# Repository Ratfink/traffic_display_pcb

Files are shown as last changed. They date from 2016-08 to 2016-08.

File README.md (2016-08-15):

# traffic_display_pcb
PCB for the Traffic Signal LED Matrix Display.

## Licensing
This work is licensed under the Creative Commons Attribution-ShareAlike 4.0
International License. To view a copy of this license, visit
http://creativecommons.org/licenses/by-sa/4.0/ or send a letter to Creative
Commons, PO Box 1866, Mountain View, CA 94042, USA.

Around half of the schematic is heavily based on the [Adafruit Feather ESP8266
HUZZAH](https://github.com/adafruit/Adafruit-Feather-ESP8266-HUZZAH-PCB).
Although Adafruit seems to have forgotten to include the exact version of the
Creative Commons Attribution-ShareAlike license used (at the time of writing),
and this project is not really a redistribution of theirs, I will include their
text as requested to try to avoid treading on any legal toes.

### Adafruit-Feather-ESP8266-HUZZAH-PCB

PCB files for the Adafruit Feather ESP8266 HUZZAH

Format is EagleCAD schematic and board layout

For more details, check out the product page at

* https://www.adafruit.com/product/2821

Adafruit invests time and resources providing this open source design, please
support Adafruit and open-source hardware by purchasing products from Adafruit!

Designed by Adafruit Industries.  
Creative Commons Attribution, Share-Alike license, check license.txt for more
information All text above must be included in any redistribution

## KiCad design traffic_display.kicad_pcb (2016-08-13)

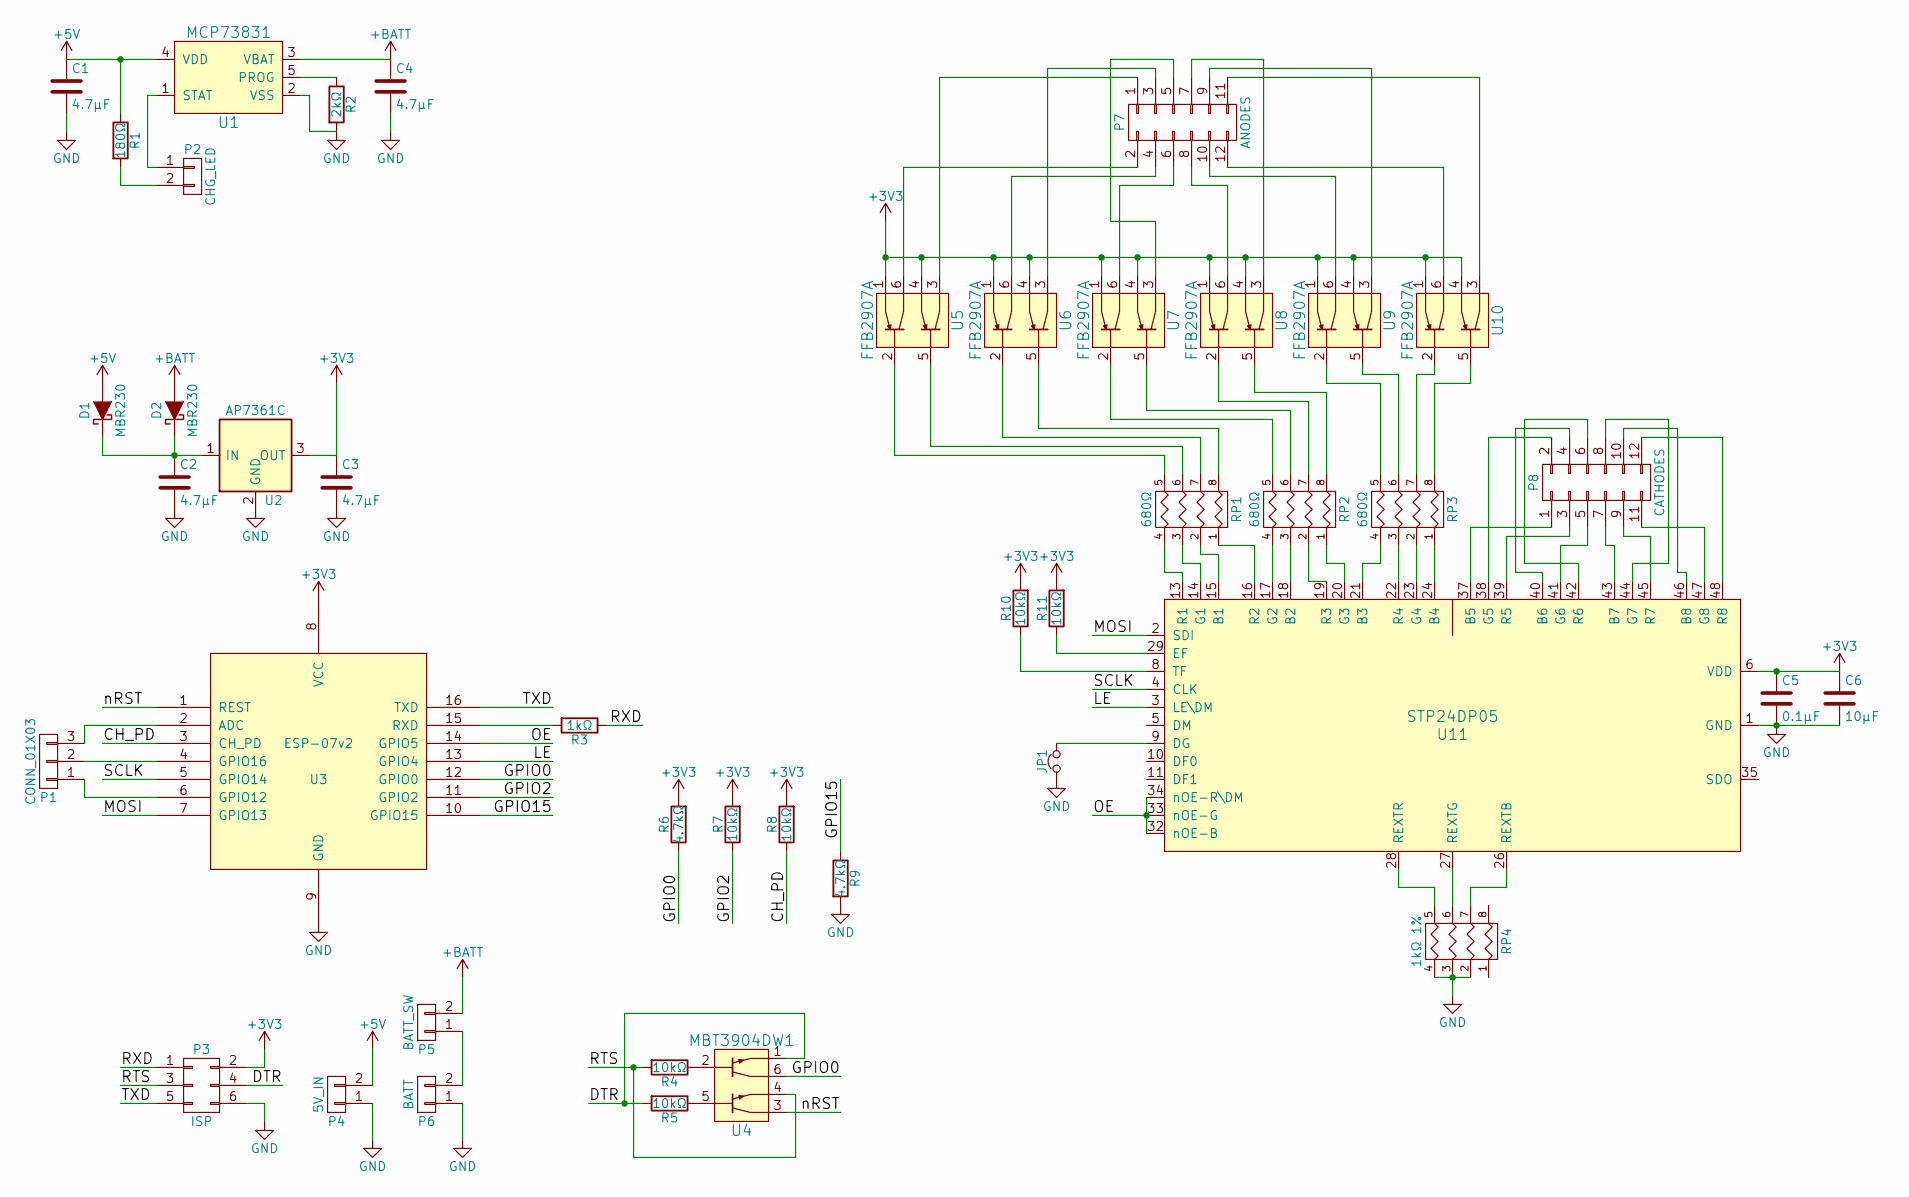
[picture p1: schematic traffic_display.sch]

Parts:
C1, C2, C3, C4: 4.7µF; C_0805_HandSoldering
C5: 0.1µF; C_0805_HandSoldering
C6: 10µF; C_0805_HandSoldering
D1, D2: MBR230; SOD-123
JP1: Jumper_NC_Small; R_0805_HandSoldering
P1: CONN_01X03; Pin_Header_Straight_1x03
P2: CHG_LED; Molex_KK-6410-02_02x2.54mm_Straight
P3: ISP; Pin_Header_Straight_2x03
P4: 5V_IN; Molex_KK-6410-02_02x2.54mm_Straight
P5: BATT_SW; Molex_KK-6410-02_02x2.54mm_Straight
P6: BATT; Molex_KK-6410-02_02x2.54mm_Straight
P7: ANODES; Pin_Header_Straight_2x06
P8: CATHODES; Pin_Header_Straight_2x06
R1: 180Ω; R_0805_HandSoldering
R2: 2kΩ; R_0805_HandSoldering
R3: 1kΩ; R_0805_HandSoldering
R4, R5, R7, R8, R10, R11: 10kΩ; R_0805_HandSoldering
R6, R9: 4.7kΩ; R_0805_HandSoldering
RP1, RP2, RP3: 680Ω; R_Array_Concave_4x0603
RP4: 1kΩ 1%; R_Array_Concave_4x0603
U1: MCP73831; SOT-23-5
U2: AP7361C; SOT-223
U3: ESP-07v2
U4: MBT3904DW1; SC-70-6_Handsoldering
U5, U6, U7, U8, U9, U10: FFB2907A; SC-70-6_Handsoldering
U11: STP24DP05; TQFP-48-1EP_7x7mm_Pitch0.5mm

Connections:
+3V3: C3.1, C5.1, C6.1, P3.2, R6.2, R7.2, R8.2, R10.2, R11.2, U2.3 (OUT), U3.8 (VCC), U5.1 (E1), U5.4 (E2), U6.1 (E1), U6.4 (E2), U7.1 (E1), U7.4 (E2), U8.1 (E1), U8.4 (E2), U9.1 (E1), U9.4 (E2), U10.1 (E1), U10.4 (E2), U11.6 (VDD), U11.31 (VDD)
+5V: C1.1, D1.2 (A), P4.2, R1.1, U1.4 (VDD)
+BATT: C4.1, D2.2 (A), P5.2, U1.3 (VBAT)
/CH_PD: R8.1, U3.3 (CH_PD)
/DTR: P3.4, R5.2, U4.1 (E1)
/GPIO0: R6.1, U3.12 (GPIO0), U4.6 (C1)
/GPIO2: R7.1, U3.11 (GPIO2)
/GPIO15: R9.1, U3.10 (GPIO15)
/LE: U3.13 (GPIO4), U11.3 (LE\DM)
/MOSI: U3.7 (GPIO13), U11.2 (SDI)
/OE: U3.14 (GPIO5), U11.32 (nOE-B), U11.33 (nOE-G), U11.34 (nOE-R\DM)
/RTS: P3.3, R4.2, U4.4 (E2)
/RXD: P3.1, R3.1
/SCLK: U3.5 (GPIO14), U11.4 (CLK)
/TXD: P3.5, U3.16 (TXD)
/nRST: U3.1 (REST), U4.3 (C2)
GND: C1.2, C2.2, C3.2, C4.2, C5.2, C6.2, JP1.1, P3.6, P4.1, P6.1, R2.2, R9.2, RP4.2, RP4.3, RP4.4, U1.2 (VSS), U2.2 (GND), U3.9 (GND), U11.1 (GND), U11.7 (GND), U11.12 (GND), U11.25 (GND), U11.30 (GND), U11.36 (GND), U11.49 (GND)
unnamed: C2.1, D1.1 (K), D2.1 (K), U2.1 (IN)
unnamed: JP1.2, U11.9 (DG)
unnamed: P1.1, U3.6 (GPIO12)
unnamed: P1.2, U3.4 (GPIO16)
unnamed: P1.3, U3.2 (ADC)
unnamed: P2.1, U1.1 (STAT)
unnamed: P2.2, R1.2
unnamed: P5.1, P6.2
unnamed: P7.1, U5.3 (C2)
unnamed: P7.2, U5.6 (C1)
unnamed: P7.3, U6.3 (C2)
unnamed: P7.4, U6.6 (C1)
unnamed: P7.5, U7.3 (C2)
unnamed: P7.6, U7.6 (C1)
unnamed: P7.7, U8.3 (C2)
unnamed: P7.8, U8.6 (C1)
unnamed: P7.9, U9.3 (C2)
unnamed: P7.10, U9.6 (C1)
unnamed: P7.11, U10.3 (C2)
unnamed: P7.12, U10.6 (C1)
unnamed: P8.1, U11.37 (B5)
unnamed: P8.2, U11.38 (G5)
unnamed: P8.3, U11.39 (R5)
unnamed: P8.4, U11.40 (B6)
unnamed: P8.5, U11.41 (G6)
unnamed: P8.6, U11.42 (R6)
unnamed: P8.7, U11.43 (B7)
unnamed: P8.8, U11.44 (G7)
unnamed: P8.9, U11.45 (R7)
unnamed: P8.10, U11.46 (B8)
unnamed: P8.11, U11.47 (G8)
unnamed: P8.12, U11.48 (R8)
unnamed: R2.1, U1.5 (PROG)
unnamed: R3.2, U3.15 (RXD)
unnamed: R4.1, U4.2 (B1)
unnamed: R5.1, U4.5 (B2)
unnamed: R10.1, U11.8 (TF)
unnamed: R11.1, U11.29 (EF)
unnamed: RP1.1, U11.16 (R2)
unnamed: RP1.2, U11.15 (B1)
unnamed: RP1.3, U11.14 (G1)
unnamed: RP1.4, U11.13 (R1)
unnamed: RP1.5 (R4), U5.2 (B1)
unnamed: RP1.6 (R3), U5.5 (B2)
unnamed: RP1.7 (R2), U6.2 (B1)
unnamed: RP1.8 (R1), U6.5 (B2)
unnamed: RP2.1, U11.20 (G3)
unnamed: RP2.2, U11.19 (R3)
unnamed: RP2.3, U11.18 (B2)
unnamed: RP2.4, U11.17 (G2)
unnamed: RP2.5 (R4), U7.2 (B1)
unnamed: RP2.6 (R3), U7.5 (B2)
unnamed: RP2.7 (R2), U8.2 (B1)
unnamed: RP2.8 (R1), U8.5 (B2)
unnamed: RP3.1, U11.24 (B4)
unnamed: RP3.2, U11.23 (G4)
unnamed: RP3.3, U11.22 (R4)
unnamed: RP3.4, U11.21 (B3)
unnamed: RP3.5 (R4), U9.2 (B1)
unnamed: RP3.6 (R3), U9.5 (B2)
unnamed: RP3.7 (R2), U10.2 (B1)
unnamed: RP3.8 (R1), U10.5 (B2)
unnamed: RP4.5 (R4), U11.28 (REXTR)
unnamed: RP4.6 (R3), U11.27 (REXTG)
unnamed: RP4.7 (R2), U11.26 (REXTB)

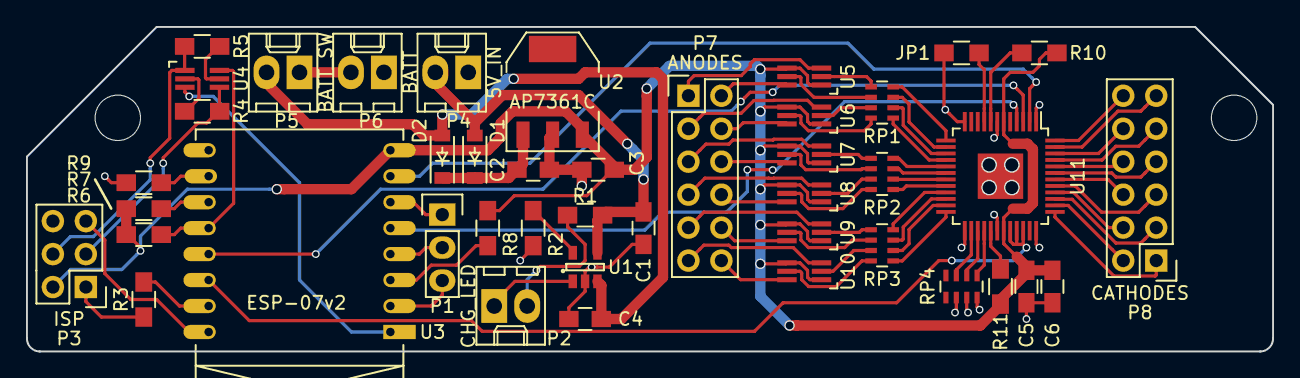
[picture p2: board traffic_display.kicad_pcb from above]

Board: 2 copper layers, 96.0 x 25.0 mm, 43 parts (0 on the bottom side), 82 nets.
